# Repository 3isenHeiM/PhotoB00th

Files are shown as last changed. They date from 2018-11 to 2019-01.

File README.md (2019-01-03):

# Photob00th

A RPi photobooth for my brother's wedding, that controls a DSLR and makes a slideshow of the pictures.

Forked from kitesurfer1404's one.

Architecture : RPI for interfacing the DSLR, with arduino to command the I/Os.

## Required features
By order of importance...
* RaspberryPi-based
* Pictures from DSLR (and not Picamera module)
* LED light (because the room will be dark)
* Press button to trigger capture
* Publish the photos as slideshow on a (remote) screen
* Countdown (7-segment display ?)
* Do a Wooden enclosure

## Design

* RaspberryPi :
  * Controls the DLSR
  * Setup the slideshow
* Arduino :
  * Wait for events on the button (+ light it up with the countdown)
  * Control the 7-segment display
  * Light and dim the big LEDs

* Serial link between Arduino and RaspberryPi to exchagne commands and feeback.
* State machine running on both µcontrollers to listen for serial commands
* Based on serial commands, they can interact

## Sources :
* [Control 7-segment display using python](https://raspi.tv/2015/how-to-drive-a-7-segment-display-directly-on-raspberry-pi-in-python)
* [Example Control big button + light](https://photos.google.com/share/AF1QipOwxhytRgeDRXFwA8Ee42yeQ1euaZ-cLYzybYsmrUi8KKORaJuT7p9L6YDLRAZysg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)
* [Instagram Filters in 15 Lines of Python](https://www.practicepython.org/blog/2016/12/20/instagram-filters-python.html)
* [Background Image](https://www.pixelstalk.net/wp-content/uploads/2016/08/Damask-Desktop-Wallpaper.jpg)

## Bill of Materials :
* [Arduino Uno - R3](https://www.sparkfun.com/products/11021) - Sparkfun - 24.95$
* [Breadboard - Self-Adhesive (White)](https://www.sparkfun.com/products/12002) - Sparkfun - 4.95$
* [Big Red dome button](https://www.sparkfun.com/products/9181) - Sparkfun - 11.95$
  12V supply
* [7-Segment display 6,5"](https://www.sparkfun.com/products/8530) - Sparkfun - 18.95$
  12V supply
* [Jumper Wires Premium 4" M/M - 26 AWG (30 Pack)](https://www.sparkfun.com/products/14284) - Sparkfun - 1.95$
  (to connect with RPi)
* [Darlington Driver 8-Channel ULN2803 DIP](https://www.sparkfun.com/products/312) - Sparkfun - 1.95$
  2 pieves
* [Jumper Wire Kit - 140pcs](https://www.sparkfun.com/products/124) - Sparkfun - 5.95$
* [DC Barrel Jack Adapter - Breadboard Compatible](https://www.sparkfun.com/products/10811) - Sparkfun - 0.95$
  to bring 12V on the breadboard
* [Resistor 1K Ohm 1/4 Watt PTH - 20 pack (Thick Leads) ](https://www.sparkfun.com/products/14492) - Sparkfun - 0.95$
* [4 LED MR16 Spotlight 12V 4W](https://www.miniinthebox.com/en/p/10pcs-dimmable-mr16-4w-4x1w-400lm-warm-white-white-cool-white-led-light-spot-lamp-dc12v_p2343919.html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) - MiniInTheBox.com - 17.38€ for 10.
* [10pc MR16 Sockets](https://www.amazon.com/Glo-shine-Halogen-Ceramic-Connector-Adapter/dp/B00Y7GRGZ0) - Amazon - 7.71$
* [Arduino and Breadboard Holder](https://www.sparkfun.com/products/11235) - Sparkfun - 3.95$

## Workflow
Here is the workflow I initially intend for this project :
1. Push the red button
2. Countdown from 3 to 0 :
    - Count using the 7-segment display
    - Light up/down the red button
    - Light the LEDs
    - At "1", ask the RPi to do the focus
    - Display the camera preview on a VGA screen
3. Trigger picture and light the LEDs more
4. Download the picture (raw/jpg?) on the RaspberryPi's external storage
5. Move a jpg version to the webserver backend
6. Reset the setup

### Arduino State machine

Initial state :
 - buttonLED is "breathing" (cf Snippets.md)
 - Wait for event on the button
 - Listening for any command in the serial port

1. When button is pressed :  
    - Display "3" on 7-segment display for 1s
    - Light the button for 0.5s
2. After 1s :
    - Display "2" on the 7-segment display for 1s
    - Light the button for 0.5s
3. After 1s :
    - Display "1" on the 7-segment display for 1s
    - ~~Send command "`do_focus`" via serial to the RPi~~
    - Light the button for 0.5s
4. Take the photo :
    - Increase lights of the LED to 100%
    - Send command "`takePhoto`" via serial to the RPi
    - ~~Wait for command "`picture_taken`" from the serial port~~
5. Get back to initial state

### Raspberry Pi State machine

Initial state :
 - ~~Waiting for command "`do_focus`" from the Arduino~~
 - Listens for the command "`takePhoto`"

1. ~~When `do_focus` is received :~~
    - ~~use gphoto to do the focus (not sure if supported)~~
2. When `takePhoto` is received :
    - use gphoto to capture the image and download it
    - ~~send `picture_taken` to Arduino~~
3. Post-process the image in a separate thread :
    - Apply a filter ? (if fast enough : 3-4s)
    - Move it the the correct folder
    - Rename it
    - Update the slideshow
4. Get back to initial state

## Various details

### PWM pins on the Arduino
Reference [here](https://www.arduino.cc/reference/en/language/functions/analog-io/analogwrite/)

On most Arduino boards (those with the ATmega168 or ATmega328P), this function works on pins `3`, `5`, `6`, `9`, `10`, and `11`.
They are indicated by a `~` besides their number on the Arduino.

### How to manipulate the button
(Learned from [here](https://learn.sparkfun.com/tutorials/reaction-timer), where they featyre the exact same button

Status :
* Button pressed : `digitalRead(button) == LOW`
* Button released : `digitalRead(button) == HIGH`

Pinning :
* *NO* (normally openned) pin : button trigger
* Anode : LED anode
* GND : ground

### Darlington arrays
Nice explanation [here](https://forum.arduino.cc/index.php?topic=157018.0)

The output of the ULN2803 is not supplying anything. The ULN2803 are a bunch of darlington transistor.
They pull the output low. That is all. They have also a large voltage drop of about 1V.

Pinning :
* 1-8 (arduino) -> 18-11 (output)  
That is :
  * `pin 1` will control whatever is conected on `pin 18`
  * `pin 2` will control the output `pin 17`
    etc...
* 10 : Common -> +12V
* Ground -> Power supply Ground

The load (led+7-segment display) has 2 connections :
* +12VDC
* output pin of the matching control pin

When the control pin is high, the Darlington array pulls down the output pin (at +12V) to the Ground. And the current flows and you have current in whatever load you have put between the Darlington output pin and the power sypply.

## Stepping stones / To-Do
- [x] Dim the 12V LEDs using the Raspberry and a Darlington array (since they are 12V-powered)   
    Solution : Use an Arduino Uno for all GPIO-related events.
- [x] DSLR is not recognized by the Ubuntu   
    Solution found [here](http://www.freeklijten.nl/2011/06/04/Mounting-a-Canon-EOS-550d-on-Ubuntu-using-gphoto2#wl-comment-672)
- [x] Auto-poweroff of the USB connectivity (tests made on MacOS)  
    Solution found [here](http://gphoto-software.10949.n7.nabble.com/canon-autopoweroff-tp14943p14958.html) : use the `wait-event` function, it send a keepalive message to the camera.
    Will be tested.
    Edit : the AutoPoweroff of the CanonESO 700D has been disabled on the Camera itself.Once done, no more interruption in the gphoto detection of the camera.
- [ ] ~~Impossible to trigger the focus of the camera itself. State machine has been updated.~~  
      Impossible to do using gphoto2.
- [ ] Handles the warning exception of skimage ()'Possible precision loss when converting from float64 to uint8')
- [ ] Threadize the post-processing

## Canon EOS 700D support
I used a Canon EOS 700D DSLR camera, the [following page](CanonEOS700D.md) lists the supported operations of gphoto for this type of camera

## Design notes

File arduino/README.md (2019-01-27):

# Arduino Photobooth

This is part of the Photob00th but might be used standalone.

The Arduino interfaces will all the GPIOs (LED, buttons, etc...) and communicates via a Serial port with the Raspberry.

The Arduino is used to be able to dim the lights of the big 4 LEDs. The dim is done using PWM modulation. I could not find any resources online to execute this on the RaspBerry (with 12V LEDs).

## State machine
cf main ReadMe.md

## Updated Wiring Diagram
The connections are done using a small breadboard.

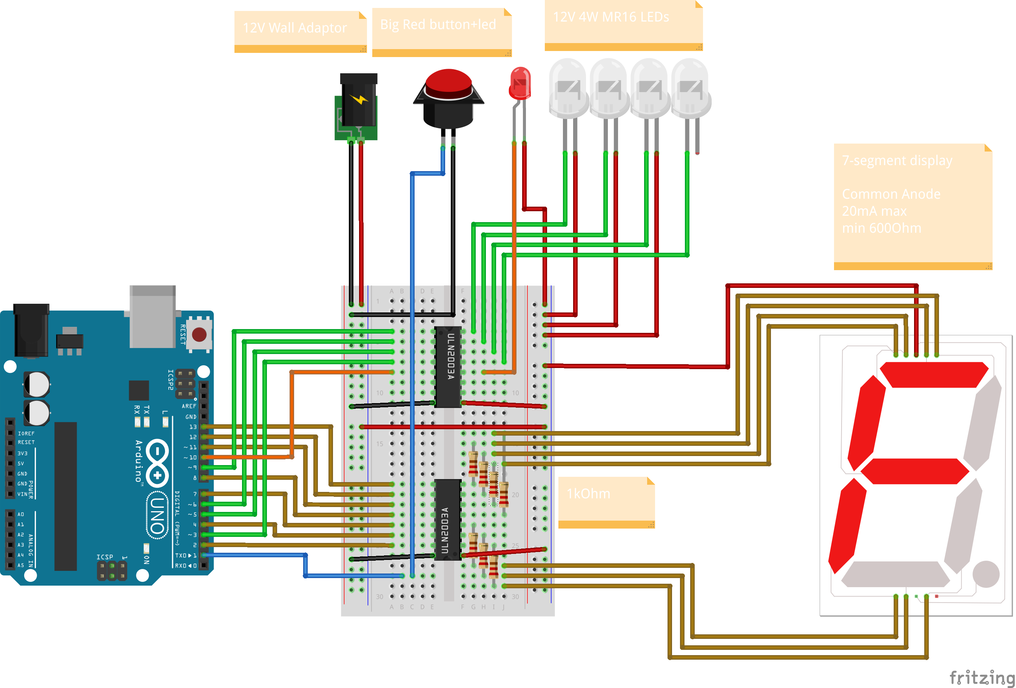
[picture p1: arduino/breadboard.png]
Arduino Photobooth


## Previous Wiring Diagram
Arduino Photobooth2

## PWM explanation
* [Controlling an LED by PWM](https://www.sunfounder.com/learn/Super-Kit-V2-0-for-Arduino/lesson-3-controlling-an-led-by-pwm-super-kit.html)
* [Fade an LED with Pulse Width Modulation using analogWrite()](https://programmingelectronics.com/tutorial-10-fade-an-led-with-pulse-width-modulation-using-analogwrite/)

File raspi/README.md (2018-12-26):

Raspberry Pi Photobooth
=======================

This part describes the setup and contains the code to be run on the RasPi.

You will need a RasPi 3 Mod. B for this setup due to image-processing-power and
WiFi capability.

If you use an older model, please adjust the WiFi as needed.

This code does NOT control the camera! Make sure the camera is triggered by
the Arduino code or cable release. The RasPi code only downloads images from the
camera after gphoto recognizes the corresponding event.

The code is mainly divided into three parts:

* slideshow running on port 8000 (http)
* script downloading and processing new images
* shutdown-script listening for pushbutton on IO for clean shutdown

photobooth.sh is the place to start your journey.

Install
-------

Install Raspian on your RasPi 3.
Setup your RasPi with raspi-config as needed. Set password.
Disable desktop if you want. Photobooth will run in terminal.

Enable SSH if needed:
```shell
sudo update-rc.d ssh defaults
sudo update-rc.d ssh enable
```

Install gphoto2 and imagemagick on your RasPi:
```shell
sudo apt install gphoto2 imagemagick libgphoto2-dev
sudo pip install pkgconfig gphoto2
```

Disable auto-mount of cameras:
```shell
sudo chmod -x /usr/lib/gvfs/gvfs-gphoto2-volume-monitor
```

Download or copy the photobooth folder to /home/pi on your RasPi.

Edit .bashrc
```shell
nano .bashrc
```

Add this to the very end:

```shell
if [ -n "$SSH_CLIENT" ] || [ -n "$SSH_TTY" ]; then
  echo "Only running on local shell."
else
  ~/photobooth/photobooth.sh
fi
```

Reboot:
```shell
sudo reboot
```

Alternatively you can add the script to the crontab and run it at reboot:

```shell
crontab -e
```

Add this line:
```
@reboot /home/pi/photobooth/photobooth.sh
```

(Adjust path accordingly)

WiFi config/AP
--------------

The RasPi is configured as a WiFi AP. This way you can connect directly to the
RasPi with your devices.

You can find a great howto here:
https://frillip.com/using-your-raspberry-pi-3-as-a-wifi-access-point-with-hostapd/

Below the bare minimum follows.

```shell
sudo apt install hostapd dnsmasq
sudo nano /etc/dhcpcd.conf
```

Add to bottom of file:
```
denyinterfaces wlan0
```

Edit network config:
```shell
sudo nano /etc/network/interfaces
```

Edit wlan0 section so it becomes this:

```
allow-hotplug wlan0
iface wlan0 inet static
    address 10.0.0.1
    netmask 255.255.255.0
    network 10.0.0.0
    broadcast 10.0.0.255
#    wpa-conf /etc/wpa_supplicant/wpa_supplicant.conf
```

Restart networking stuff

```shell
sudo service dhcpcd restart
sudo ifdown wlan0; sudo ifup wlan0
```

Edit hostapd config.

```shell
sudo nano /etc/hostapd/hostapd.conf
```

Please adjust WiFi ssid and password to your needs.

```
ssid=Photobooth-WiFi
wpa_passphrase=Smile123456
interface=wlan0
driver=nl80211
hw_mode=g
channel=6
ieee80211n=1
wmm_enabled=1
ht_capab=[HT40][SHORT-GI-20][DSSS_CCK-40]
macaddr_acl=0
auth_algs=1
ignore_broadcast_ssid=0
wpa=2
wpa_key_mgmt=WPA-PSK
rsn_pairwise=CCMP
```

Test
```shell
sudo /usr/sbin/hostapd /etc/hostapd/hostapd.conf
```

You should now see Photobooth-WiFi floating around. Quit:
```shell
Ctrl-C
```

Start WiFi AP as daemon:
```shell
sudo nano /etc/default/hostapd
```

Edit config to
```
DAEMON_CONF="/etc/hostapd/hostapd.conf"
```

Let's make sure we even get an IP address when using the WiFi:
```shell
sudo mv /etc/dnsmasq.conf /etc/dnsmasq.conf.orig
sudo nano /etc/dnsmasq.conf
```

```
interface=wlan0      # Use interface wlan0
listen-address=10.0.0.1 # Explicitly specify the address to listen on
bind-interfaces      # Bind to the interface to make sure we aren't sending things elsewhere
server=10.0.0.1      # Answer DNS request by self
domain-needed        # Don't forward short names
bogus-priv           # Never forward addresses in the non-routed address spaces.
dhcp-range=10.0.0.50,10.0.0.150,24h # Assign IP addresses between 10.0.0.50 and 10.0.0.150 with a 24 hour lease time
```

```shell
sudo service hostapd start
sudo service dnsmasq start
```

Check. Double check.

```shell
sudo reboot
```

Check again.

Shutdown script
---------------

We need a nice shutdown of the RasPi so no data is getting lost. I wrote a small
shutdown.py script that listens to one of the IO-pins. If pin is connected to
GND, the script calls sudo halt.

Connect a momentary switch between Pin 26 and GND on the GPIOs.

If you want to skip this, shutdown with a keyboard or so.

You might also want to try to add dtoverlay=gpio-shutdown,gpio-pin=X to /boot/config.txt (Thanks to @sxwid) instead of using the shutdown script.

(Almost) Done!
--------------

Please refer to the gphoto section below for gphoto setup for your specific camera model!

You might then reboot and enjoy the photobooth slideshow on
http://10.0.0.1:8000

Detailed information on the Hows and Whys
=========================================

Main Control
------------

All needed processes are started by photobooth.sh which runs at startup.

gphoto
------

All the communication with the camera is done by gphoto2.
Please check their documentation to get your camera hooked up.

Photos are stored on the cameras memory card. This is set in photobooth.sh with:

```shell
gphoto2 --set-config-index /main/settings/capturetarget=1
```

You might want to adjust that command to your camera needs. Find the right
capturetarget with this command and identify the correct choice:

```shell
gphoto2 --get-config=capturetarget
```

```
Label: Capture Target                                                          
Type: RADIO
Current: Internal RAM
Choice: 0 Internal RAM
*Choice: 1 Memory card*
```

Try to set manually:

```shell
gphoto2 --set-config-index /main/settings/capturetarget=1
```

Check:

```shell
gphoto2 --get-config=capturetarget
```

```
Label: Capture Target                                                          
Type: RADIO
*Current: Memory card*
Choice: 0 Internal RAM
Choice: 1 Memory card
```

**Update photobooth.sh to your needs.**

gphoto waits for a photo to be taken and then downloads the photo to the
RasPi. After downloading, the images are processed by postprocessing.sh

You can test this manually if needed:

```shell
gphoto2 --wait-event-and-download --keep --hook-script=postprocessing.sh
```

At the moment RAW-files are just moved to images/raw
JPEGs are processed with imagemagicks convert command. You might want to check
the options in postprocessing.sh and adjust them to your needs.

Slideshow
---------

There is a minimal webserver running on port 8000. See server.py for details.
index.html redirects the viewer to the slideshow.

Mainly it is requesting the image-count on the RasPi and enques all new images
to the slideshow. This is done by an ajax-request for /image_count.txt on the
server. Then filenames and paths are generated in javascript.
Take a look at slideshow/index.html and the JS-vars image_path and image_extension
You need to adjust these to chances in the postprocessing.sh accordingly.

The slideshow is optimized for 1920x1080 screens.
Modify #slideshow and #slideshow img in slideshow.css to your needs.

Credits for the Ken Burns effect go to:

http://cssmojo.com/ken-burns-effect/
http://www.css-101.org/articles/ken-burns_effect/css-transition.php

### Image resising

resize.py takes car of resinsing the image to a FullHD (1920x1080). Inspired from [here](https://www.blog.pythonlibrary.org/2017/10/12/how-to-resize-a-photo-with-python/)
```
# python resize.py
  Original image : 5184x3456
  Scaled image : 1920x1280
  Elapsed time: 1.178s
```

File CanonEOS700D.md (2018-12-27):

# Canon EOS 700D and gphoto2

` gphoto2 --capture-image-and-download --filename "%Y-%m-%d %H:%M:%S.jpg" `

## Supported operations
```
gphoto2 --list-config
/main/actions/syncdatetimeutc
/main/actions/syncdatetime
/main/actions/uilock
/main/actions/autofocusdrive
/main/actions/manualfocusdrive
/main/actions/cancelautofocus
/main/actions/eoszoom
/main/actions/eoszoomposition
/main/actions/viewfinder
/main/actions/eosremoterelease
/main/actions/opcode
/main/settings/datetimeutc
/main/settings/datetime
/main/settings/reviewtime
/main/settings/output
/main/settings/movierecordtarget
/main/settings/evfmode
/main/settings/ownername
/main/settings/artist
/main/settings/copyright
/main/settings/customfuncex
/main/settings/focusinfo
/main/settings/focusarea
/main/settings/autopoweroff
/main/settings/depthoffield
/main/settings/capturetarget
/main/settings/capture
/main/status/serialnumber
/main/status/manufacturer
/main/status/cameramodel
/main/status/deviceversion
/main/status/vendorextension
/main/status/model
/main/status/ptpversion
/main/status/Battery Level
/main/status/batterylevel
/main/status/lensname
/main/status/eosserialnumber
/main/status/shuttercounter
/main/status/availableshots
/main/imgsettings/imageformat
/main/imgsettings/imageformatsd
/main/imgsettings/iso
/main/imgsettings/whitebalance
/main/imgsettings/colortemperature
/main/imgsettings/whitebalanceadjusta
/main/imgsettings/whitebalanceadjustb
/main/imgsettings/whitebalancexa
/main/imgsettings/whitebalancexb
/main/imgsettings/colorspace
/main/capturesettings/exposurecompensation
/main/capturesettings/focusmode
/main/capturesettings/continuousaf
/main/capturesettings/aspectratio
/main/capturesettings/storageid
/main/capturesettings/highisonr
/main/capturesettings/autoexposuremode
/main/capturesettings/drivemode
/main/capturesettings/picturestyle
/main/capturesettings/aperture
/main/capturesettings/shutterspeed
/main/capturesettings/meteringmode
/main/capturesettings/bracketmode
/main/capturesettings/aeb
/main/other/d402
/main/other/d407
/main/other/d406
/main/other/d303
/main/other/5001
```

## Various operations

### Battery Level
I think that the camera is powered by the UBS cable, so there's no worry about running out of battery when it's USB-connected.
```
# gphoto2 --get-config batterylevel
Label: Battery Level
Readonly: 1
Type: TEXT
Current: 100%
END
```
### AutoPowerOff

```
# gphoto2 --get-config autopoweroff
Label: Auto Power Off
Readonly: 0
Type: TEXT
Current: 30
END
```

### Set Manual Focus
`--set-config manualfocusdrive=Mode` where mode is "Near 1" "Near 2" "Near 3" "Far 1" "Far 2" "Far 3".
These are 3 different relative stepsizes for both focusing directions. To achieve focusing, multiple calls might need to be done.

### Time difference

1. Capture target on internal memory   
`gphoto2 --set-config-index /main/settings/capturetarget=0`  

```
time gphoto2 --capture-image-and-download --filename "%Y-%m-%d_%H:%M:%S.jpg"
New file is in location /capt0000.jpg on the camera
Saving file as 2018-11-30_20:18:22.jpg
Deleting file /capt0000.jpg on the camera
gphoto2 --capture-image-and-download --filename "%Y-%m-%d_%H:%M:%S.jpg"  0.14s user 0.11s system 7% cpu 3.431 total
```
2. Capture target on SD card
`gphoto2 --set-config-index /main/settings/capturetarget=1`  

```
time gphoto2 --capture-image-and-download --filename "%Y-%m-%d_%H:%M:%S.jpg"
New file is in location /store_00020001/DCIM/100CANON/IMG_2523.JPG on the camera
Saving file as 2018-11-30_21:22:42.jpg
Deleting file /store_00020001/DCIM/100CANON/IMG_2523.JPG on the camera
gphoto2 --capture-image-and-download --filename "%Y-%m-%d_%H:%M:%S.jpg"  0.13s user 0.15s system 4% cpu 6.517 total
```

## Useful links
* [gphoto on MacOS](http://photolifetoys.blogspot.com/2012/08/control-your-camera-with-gphoto2-via.html)

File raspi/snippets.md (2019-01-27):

# Code snippets

Those are a collection of snippets I fetched during my investigation on how to do it...

---
## List the capabilities of a camera :
`gphoto2 --list-all-config >config.txt`

Display `config.txt` to see what is supported.

---
## Disable IPv6 on Raspberry
Reference [here](https://askubuntu.com/a/309463/217297)

---
## Python Serial port and commands
Reference [here](https://stackoverflow.com/questions/676172/full-examples-of-using-pyserial-package)

```
import time
import serial

# configure the serial connections (the parameters differs on the device you are connecting to)
ser = serial.Serial(
    port='/dev/ttyUSB1',
    baudrate=9600,
    parity=serial.PARITY_ODD,
    stopbits=serial.STOPBITS_TWO,
    bytesize=serial.SEVENBITS
)

ser.isOpen()

print 'Enter your commands below.\r\nInsert "exit" to leave the application.'

input=1
while 1 :
    # get keyboard input
    input = raw_input(">> ")
        # Python 3 users
        # input = input(">> ")
    if input == 'exit':
        ser.close()
        exit()
    else:
        # send the character to the device
        # (note that I happend a \r\n carriage return and line feed to the characters - this is requested by my device)
        ser.write(input + '\r\n')
        out = ''
        # let's wait one second before reading output (let's give device time to answer)
        time.sleep(1)
        while ser.inWaiting() > 0:
            out += ser.read(1)

        if out != '':
          print ">>" + out
```

---
## Capture and download using python

From python-gphoto2 [examples](https://github.com/jim-easterbrook/python-gphoto2/blob/master/examples/capture-image.py).
Two functions are used :
* `gp.gp_camera_capture(camera, gp.GP_CAPTURE_IMAGE)`  
to trigger the shot
* `gp.gp_camera_file_get(camera, file_path.folder, file_path.name, gp.GP_FILE_TYPE_NORMAL)`  
to download the image

```
#!/usr/bin/env python

# python-gphoto2 - Python interface to libgphoto2
# http://github.com/jim-easterbrook/python-gphoto2
# Copyright (C) 2015-17  Jim Easterbrook  jim@jim-easterbrook.me.uk
#
# This program is free software: you can redistribute it and/or modify
# it under the terms of the GNU General Public License as published by
# the Free Software Foundation, either version 3 of the License, or
# (at your option) any later version.
#
# This program is distributed in the hope that it will be useful,
# but WITHOUT ANY WARRANTY; without even the implied warranty of
# MERCHANTABILITY or FITNESS FOR A PARTICULAR PURPOSE.  See the
# GNU General Public License for more details.
#
# You should have received a copy of the GNU General Public License
# along with this program.  If not, see <http://www.gnu.org/licenses/>.

from __future__ import print_function

import logging
import os
import subprocess
import sys

import gphoto2 as gp

def main():
    logging.basicConfig(
        format='%(levelname)s: %(name)s: %(message)s', level=logging.WARNING)
    gp.check_result(gp.use_python_logging())
    camera = gp.check_result(gp.gp_camera_new())
    gp.check_result(gp.gp_camera_init(camera))
    print('Capturing image')
    file_path = gp.check_result(gp.gp_camera_capture(
        camera, gp.GP_CAPTURE_IMAGE))
    print('Camera file path: {0}/{1}'.format(file_path.folder, file_path.name))
    target = os.path.join('/tmp', file_path.name)
    print('Copying image to', target)
    camera_file = gp.check_result(gp.gp_camera_file_get(
            camera, file_path.folder, file_path.name, gp.GP_FILE_TYPE_NORMAL))
    gp.check_result(gp.gp_file_save(camera_file, target))
    subprocess.call(['xdg-open', target]) # To open the image in the preferred editor
    gp.check_result(gp.gp_camera_exit(camera))
    return 0

if __name__ == "__main__":
sys.exit(main())
```

---
## Serial communication with an Arduino

from [here](https://stackoverflow.com/a/24075787/3494633)

```
#!/usr/bin/python
import serial
import syslog
import time

#The following line is for serial over GPIO
port = '/dev/tty.usbmodem1411' # note I'm using Mac OS-X

ard = serial.Serial(port,9600,timeout=5)
time.sleep(2) # wait for Arduino

i = 0

while (i < 4):
    # Serial write section

    setTempCar1 = 63
    setTempCar2 = 37
    ard.flush()
    setTemp1 = str(setTempCar1)
    setTemp2 = str(setTempCar2)
    print ("Python value sent: ")
    print (setTemp1)
    ard.write(setTemp1)
    time.sleep(1) # I shortened this to match the new value in your Arduino code

    # Serial read section
    msg = ard.read(ard.inWaiting()) # read all characters in buffer
    print ("Message from arduino: ")
    print (msg)
    i = i + 1
else:
    print "Exiting"
exit()
```

---
## Resize image to 1080p

`resize.py` takes car of resizing the image to a FullHD (1920x1080). Inspired from [here](https://www.blog.pythonlibrary.org/2017/10/12/how-to-resize-a-photo-with-python/)
```
# python resize.py
  Original image : 5184x3456
  Scaled image : 1920x1280
  Elapsed time: 1.178s
```

resize.py :
```
from PIL import Image
import time

def scale_image(input_image_path,
                output_image_path,
                width=None,
                height=None
                ):
    original_image = Image.open(input_image_path)
    w, h = original_image.size
    print('Original image : {wide}x{height} '
          'high'.format(wide=w, height=h))

    if width and height:
        max_size = (width, height)
    elif width:
        max_size = (width, h)
    elif height:
        max_size = (w, height)
    else:
        # No width or height specified
        raise RuntimeError('Width or height required!')

    original_image.thumbnail(max_size, Image.ANTIALIAS)
    original_image.save(output_image_path)

    scaled_image = Image.open(output_image_path)
    width, height = scaled_image.size
    print('Scaled image : {wide}x{height} '
          'high'.format(wide=width, height=height))

if __name__ == '__main__':

    start = time.time()

    scale_image(input_image_path='2018-11-30_20:12:39.jpg',
                output_image_path='2018-11-30_20:12:39_scaled.jpg',
                width=1920)

    elapsed = time.time() - start
    print 'Elapsed time: %.3fs' % (elapsed)
```

---
## Standalone Photobooth using RPi only

from [here](https://github.com/feiticeir0/RPiPhotoBooth/blob/master/RPiPhotoBooth.py)

```
# Testing here
while (True):
	try:
		camera.start_preview()      # <--- To be replaced by the libphoto function
		#Show LED Only for Take Picture
		onlyTakePicLed()
		# Wait for button to take Picture
		GPIO.wait_for_edge(takeButton,GPIO.FALLING)
		# Start a thread to count with the LEDs while the images are shown
		# Probably could be used in the overlayCounter function,
		# because it also as timers to show the pictures, but the led effects would not
		# be the same
		thread.start_new_thread ( countingTimerPicture,() )

		# Show the pictures overlay in the camera picture
		overlayCounter()
		# Show all LEDS while taking the picture
		showAllLeds()

		# Define a filename and path
		filename = "fotos/%s.jpg" % (time.strftime("%G%m%d%H%M%S"))
		# camera.capture('pushTesting.jpg')
		camera.capture(filename)
		camera.stop_preview()

		#display image
		# Resize and display the resized one
		#filename_t = "fotos/resized_t.jpg"
		# resizeThumbnail(filename)
		displayPreview(filename)
		# Show overlay
		oo = overlaysn()
		# While not choosing an option
		### Add a callback
		####GPIO.add_event_detect(socialNetworkButton,GPIO.FALLING,callback=tweetImage,bouncetime=300)
		###while (True):
		###	GPIO.wait_for_edge(cancelButton, GPIO.FALLING)
		####	print ("cancelled Button")
		##	break
		# Show LEDs to Cancel or Post to Social Networks
		cancelPostLEDS()
		GPIO.add_event_detect(socialNetworkButton,GPIO.FALLING)
		GPIO.add_event_detect(cancelButton,GPIO.FALLING)
		while (True):
			if GPIO.event_detected(socialNetworkButton):
				camera.remove_overlay(oo)
				GPIO.output(cancelButtonLed,False)
				o = displayPreview3('Aenviar.png')
				#print "Social Networks Button"
				# add watermark
				# Only add watermark if sending to social networks
				addWaterMark()
				sendToTwitter()
				sendToFacebook()
				camera.remove_overlay(o)
				break
			if GPIO.event_detected(cancelButton):
				#print "Canceled"
				camera.remove_overlay(oo)
				break

		# reset GPIOS
		GPIO.remove_event_detect(socialNetworkButton)
		GPIO.remove_event_detect(cancelButton)
		GPIO.remove_event_detect(takeButton)
		camera.stop_preview()
	except KeyboardInterrupt:
		print ("Exited...")
		#offLeds()
GPIO.cleanup()
```

---

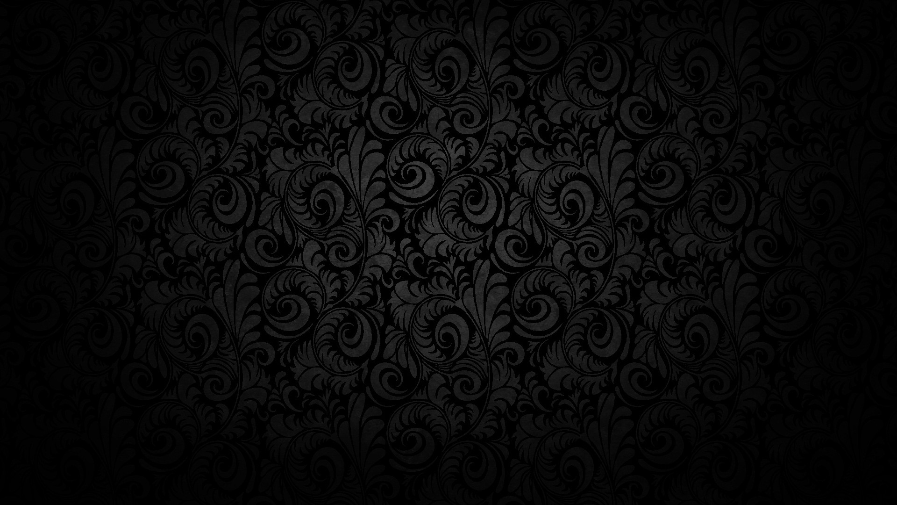
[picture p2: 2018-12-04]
raspi/photobooth/slideshow/background_3.jpg

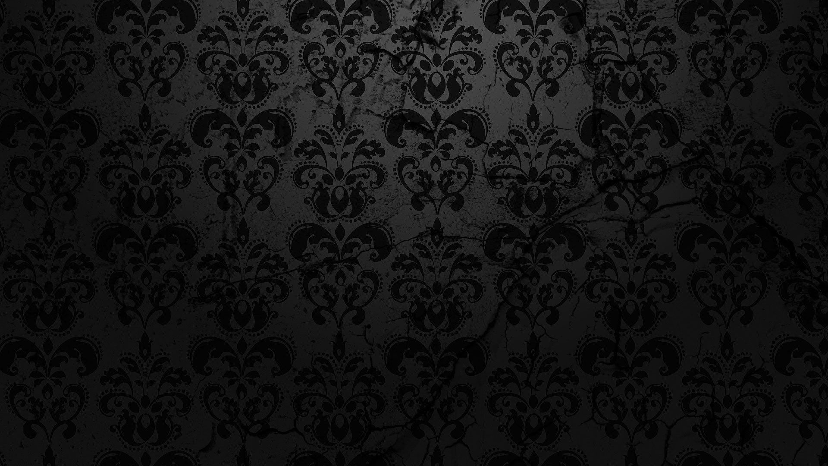
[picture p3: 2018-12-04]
raspi/photobooth/slideshow/background_2.jpg

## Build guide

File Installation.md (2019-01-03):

# Installation

For the original project I used an Odroid C2 instead of a RapsberryPi 3B+.

This is thus divide din to 2 parts :
* Installation on Odroid C2
* Installation on raspberry Pi

## Installation on Odroid C2

### Python modules to Install

To be installed using pip (`pip install <package_name>`) :
* pyserial
* RPi.GPIO

### Installation of GPhoto

Installation of libgphoto-device
`$ sudo apt install gphoto2 libgphoto2-dev`

Installation of gphoto using pip (from [here](https://github.com/jim-easterbrook/python-gphoto2#install-with-pip))
`$ sudo pip install gphoto2`

### Use RPi.GPIO

TO use the GPIOs on the Odroid C2, first we have to install a library to allow us to use the same library as for the Rapsberry Pi. Useful doc is (here)[https://github.com/jfath/RPi.GPIO-Odroid]

### Installation of Skimage
1. Install SciPy following [this guide](https://www.scipy.org/install.html). Basically running this (it will download approx 1.6 GB data !):  
`sudo apt-get install python-numpy python-scipy python-matplotlib ipython python-pandas python-sympy python-nose`

2. Install Cython (required to build scikit-image)  
`sudo apt install cython`

3. Install `scikit-image` (new version of `skimage`)  
`sudo pip install scikit-image`

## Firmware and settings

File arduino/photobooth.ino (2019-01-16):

/*
  Arduino Photobooth

  FEATURES
    * 7-segment-display for countdown
    * LED-speedlights
    * "breathing" pushbutton-LED
    * Standalone or remote controlled operation (USB-serial)


  NOTES
    * Pushbutton-pins are configured to use internal pullup resistors
      of the Arduino for less external parts. If you want to use external
      pullup resistors change INPUT_PULLUP to INPUT in setup().
    * Set your camera to continuous focus for best results.
    * Use exposure compensation to compensate the dimmed focusing light.
      Values arround -1 EV work best for me in low light situations.
    * You might also need to adjust values in takePhoto() to your needs.
      Brightness and delays might be different with different LED-bulbs.
    * Serial speed is 9600 Baud. See processCommand() for a complete
      list of supported commands.
    * There is support for multiple pushbuttons - although only one is used
      by now. When connecting to a Raspberry Pi a second pushbutton might be
      used to shut the Pi down due to its lack of a power-down-button.
    * analogWrite() works only on Pins 3, 5, 6, 9, 10, 11 - that's why the LED-spots
      are connected to pins 10, 11, 5, 6 so we can get dimmed focusing light.
    * Make sure to connect all pushbutton LEDs to PWM outputs so the breathing
      will work.
    * Read the datasheet of your 7-segment-display for pin-layout.
      Connect this way:

       Segment     Pin (7-segment) Pin (Darlington)    Pin (Arduino)
          A         1               1-18                13
          B         8               4                   8
          C         7               7                   2
          D         6               6                   4
          E         4               5                   7
          F         2               2                   12
          G         3               3                   11
          DP        9               --

      Use darlington array and and current limiting resistors as appropriate.
    * See repository for example circuit.

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

  LICENSE

  The MIT License (MIT)

  Copyright (c) 2015  Harm Aldick

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

  CHANGELOG

  2016-01-16   Initial beta release

*/


/* This is where you might define different IO-pins */

int segment_pins[] = { 8, 2, 13, 4, 7, 12, 11}; // pins segments A-G of the display are connected to
//int segment_pins[] = { 13, 8, 2, 4, 7, 12, 11}; // pins segments A-G of the display are connected to
int spot_pins[] = { 9, 6, 5, 3};             // pins the spot-lights are connected to, use PWM-pins here

// TODO : check numbering of the A0 pin of the Arduino
int button_led[] = { 10 };  // pin on which the LED of the pushbutton-switch is connected to. Use PWM-pins here.
int button_pin[] = { 1 }; // pin on which the pushbutton(s) is/are connected to. Using analog pin A0 as digital input
int lastButtonState[] = { 1 };  // saving the last state(s) of the button(s)


/* Some magic configuration happening below. */

byte segment_digits[10][7] = { // segments to light up on the corresponding index
  { 1,1,1,1,1,1,0 },    // 0
  { 0,1,1,0,0,0,0 },    // 1
  { 1,1,0,1,1,0,1 },    // 2
  { 1,1,1,1,0,0,1 },    // 3
  { 0,1,1,0,0,1,1 },    // 4
  { 1,0,1,1,0,1,1 },    // 5
  { 1,0,1,1,1,1,1 },    // 6
  { 1,1,1,0,0,0,0 },    // 7
  { 1,1,1,1,1,1,1 },    // 8
  { 1,1,1,1,0,1,1 }     // 9
};

int breath_delay_steps[] =       {   7,   9,  13, 15, 16, 17, 18, 930, 19, 18, 15, 13,   9,   7,   4,   5 }; // magic numbers for breathing LED
int breath_brightness_steps[] =  { 150, 125, 100, 75, 50, 25, 16,  15, 16, 25, 50, 75, 100, 125, 150, 220 }; // even more magic numbers!

// initial/default values for breathing LED
#define breath_initial_brightness 15
#define breath_initial_direction 1
#define breath_initial_index 8
#define breath_initial_delay 1

int breath_brightness; // initial brightness of breathing LED
int breath_direction;  // increase brightness
int breath_index;      // start at index 8 of our magic numbers
int breath_delay;      // no delay at startup, load values imidiately
boolean breathing_enabled = true;  // enables/disables breathing LED at all.

String inputCommand = "";         // a string to hold incoming data from serial
boolean commandComplete = false;  // whether the command string is complete

boolean mode_auto = true; // default is running in standalone-mode



// The setup function runs once when you press reset or power the board.
void setup() {
  // Set all 7-segment-pins as output and turn LEDs off
  for(int i = 0; i < sizeof(segment_pins)/sizeof(int); i++) {
    pinMode(segment_pins[i], OUTPUT);
    digitalWrite(segment_pins[i], LOW);
  }

  // Turn all spotsOff.
  for(int i = 0; i < sizeof(spot_pins)/sizeof(int); i++) {
    digitalWrite(spot_pins[i], 0);
  }

  // Set all pushbutton-LED-pins as output and turn LEDs off
  for(int i = 0; i < sizeof(button_led)/sizeof(int); i++) {
    pinMode(button_led[i], OUTPUT);
    digitalWrite(button_led[i], LOW);
  }

  // Set all pushbutton-pins as input and enable pullup resistor
  for(int i = 0; i < sizeof(button_pin)/sizeof(int); i++) {
    pinMode(button_pin[i], INPUT_PULLUP); // change INPUT_PULLUP to INPUT when there is an external pullup-resistor attached
  }

  Serial.begin(115200); // initialize serial

  inputCommand.reserve(100); // reserve 100 bytes for the inputCommand

  breathing_reset(); // reset breathing LEDs

  Serial.println("ready"); // we're ready to rock!
}


/* turns all breathing LEDs gently on and resets everything for restart breathing */
void breathing_reset() {
  for(int i = 0; i <= 15; i++) {
    for(int p = 0; p < sizeof(button_led)/sizeof(int); p++) {
      analogWrite(button_led[p], i);
    }
    delay(10);
  }

  breathing_enabled = true;
  breath_brightness = breath_initial_brightness;
  breath_direction = breath_initial_direction;
  breath_index = breath_initial_index;
  breath_delay = breath_initial_delay;
}


/* turns all breathing LEDs off and disables breathing at all */
void breathing_stop() {
  for(int i = 0; i < sizeof(button_led)/sizeof(int); i++) {
    analogWrite(button_led[i], 0);
  }
  breathing_enabled = false;
}


/* does one step in "breathing", so we don't block anything else too long. */
void breathing_do_step() {
  if(!breathing_enabled) {
    return;  // nothing to do if disabled
  }

  breath_delay--;

  // update brightness and delays when waited long enough
  if(breath_delay == 0) {
    // increase or decrese brightness
    breath_brightness = breath_brightness + breath_direction;

    // change direction when LED is fully lit or very dimm
    if(breath_brightness == 255 || breath_brightness == 15) {
      breath_direction *= -1;
    }

    // update index of current delay when target brightness is reached
    if(breath_brightness == breath_brightness_steps[breath_index]) {
      breath_index++;

      // start over when the end is reached
      if(breath_index == sizeof(breath_brightness_steps)/sizeof(int)) {
        breath_index = 0;
      }
    }

    // get new delay
    breath_delay = breath_delay_steps[breath_index];

    // set new brightness to all pushbutton leds
    for(int i = 0; i < sizeof(button_led)/sizeof(int); i++) {
      analogWrite(button_led[i], breath_brightness);
    }

  } else {
    delay(1); // if we have still some rounds to go, wait 1ms and return
  }
}


/* flashes the 7-segment-display in a fancy way */
void animation_one(int wait) {
  for (int i = 0; i < sizeof(segment_pins)/sizeof(int); i++) {
    digitalWrite(segment_pins[i], LOW);
  }

  for(int n = 0; n < 5; n++) {
    for (int i = 0; i < 6; i++) {
      digitalWrite(segment_pins[i], HIGH);
      delay(wait);
      digitalWrite(segment_pins[i], LOW);
    }
  }
}


/* flashes the 7-segment-display in another fancy way */
void animation_two(int wait) {
  int animation[] = { 1, 2, 7, 5, 4, 3, 7, 6 };

  for (int i = 0; i < sizeof(segment_pins)/sizeof(int); i++) {
    digitalWrite(segment_pins[i], LOW);
  }

  for(int n = 0; n < 5; n++) {
    for(int i = 0; i < 8; i++) {
      int segment = animation[i] - 1;
      digitalWrite(segment_pins[segment], HIGH);
      delay(wait);
      digitalWrite(segment_pins[segment], LOW);
    }
  }
}


/* flashes the spots in a fancy way */
void animation_spots(int wait) {
  for (int i = 0; i < sizeof(spot_pins)/sizeof(int); i++) {
    spot_off(i);
  }

  for (int i = 0; i < sizeof(spot_pins)/sizeof(int); i++) {
    spot_on(i);
    delay(wait);
    spot_off(i);
  }
}


/* turns the LED on the button on */
void button_led_on(){
  for(int i = 0; i < sizeof(button_led)/sizeof(int); i++) {
    analogWrite(button_led[i], 255);
  }
}


/* turns the LED on the button on */
void button_led_off(){
  for(int i = 0; i < sizeof(button_led)/sizeof(int); i++) {
    analogWrite(button_led[i], 0);
  }
}

/* turns a single spot on */
void spot_on(int i) {
  analogWrite(spot_pins[i], 255);
}


/* turns a single spot off */
void spot_off(int i) {
  analogWrite(spot_pins[i], 0);
}


/* turns all spotsOn ("speedlight") */
void spots_on() {
  for (int i = 0; i < sizeof(spot_pins)/sizeof(int); i++) {
    spot_on(i);
  }
}


/* turns all spotsOff */
void spots_off() {
  for (int i = 0; i < sizeof(spot_pins)/sizeof(int); i++) {
    spot_off(i);
  }
}


/* turns all spotsOn (dimmed) for fucusing the camera in low light */
void spots_dimm(int value) {
  for (int i = 0; i < sizeof(spot_pins)/sizeof(int); i++) {
    analogWrite(spot_pins[i], value);
  }
}




/* displays a number on the 7-segment-display */
void displayNumber(int n) {
  for (int i = 0; i < sizeof(segment_pins)/sizeof(int); i++) {
    digitalWrite(segment_pins[i], segment_digits[n][i]);
  }
}


/* turns the 7-segment-displayOff */
void display_off() {
  for (int i = 0; i < sizeof(segment_pins)/sizeof(int); i++) {
    digitalWrite(segment_pins[i], LOW);
  }
}


/* turns every light off */
void clearAll() {
  spots_off();
  display_off();
  breathing_stop();
}


/* starts countdown and focusing, than takes picture */
void takePhoto() {
  //Serial.println("Taking photo.");

  animation_one(50);

  spots_dimm(5);

  // Display 3 and light the button_led
  button_led_on();
  displayNumber(3);
  delay(500);

  // Switch the button_led off
  button_led_off();
  delay(500);

  // Display a 2 and light the button_led
  button_led_on();
  displayNumber(2);
  delay(500);

  // Switch the button_led off
  button_led_off();
  delay(500);

  // Display a 1 and light the button_led
  button_led_on();
  displayNumber(1);
  delay(500);

  // Switch the button_led off
  button_led_off();
  delay(300);
  display_off();

  button_led_on();

  // Slight increase of the luminosity
  spots_dimm(20);
  delay(50);
  spots_dimm(40);
  delay(50);
  spots_dimm(60);
  delay(50);
  spots_dimm(80);
  delay(50);

  // Triggers camera on the RaspberryPi
  Serial.println("takePhoto");

  // Make the LED button blink
  for (int i = 0; i < 15; i++) {
    button_led_off();
    delay(50);
    button_led_on();
    delay(50);
  }

  // Full brightness of the LED spots
  spots_on();

  // Make the LED button blink
  for (int i = 0; i < 10; i++) {
    button_led_off();
    delay(50);
    button_led_on();
    delay(50);
  }

  delay(500);
  spots_dimm(80);
  delay(50);
  spots_dimm(60);
  delay(50);
  spots_dimm(40);
  delay(50);
  spots_dimm(20); 
  delay(50);
  spots_dimm(5);
  delay(50); 
  
  
  clearAll();

  //Serial.println("Photo taken.");
}


/* checks received command and calls corresponding function */
void processCommand(String cmd) {
  if(cmd == "1") displayNumber(1);
  if(cmd == "2") displayNumber(2);
  if(cmd == "3") displayNumber(3);
  if(cmd == "4") displayNumber(4);
  if(cmd == "5") displayNumber(5);
  if(cmd == "6") displayNumber(6);
  if(cmd == "7") displayNumber(7);
  if(cmd == "8") displayNumber(8);
  if(cmd == "9") displayNumber(9);
  if(cmd == "0") displayNumber(0);

  if(cmd == "displayOff") display_off();

  if(cmd == "spotsOn") spots_on();
  if(cmd == "spotsOff") spots_off();
  if(cmd == "spotsDimm") spots_dimm(1);

  if(cmd == "S1_on") spot_on(0);
  if(cmd == "S1_off") spot_off(0);
  if(cmd == "S2_on") spot_on(1);
  if(cmd == "S2_off") spot_off(1);
  if(cmd == "S3_on") spot_on(2);
  if(cmd == "S3_off") spot_off(2);
  if(cmd == "S4_on") spot_on(3);
  if(cmd == "S4_off") spot_off(3);

  if(cmd == "animation1") animation_one(50);
  if(cmd == "animation2") animation_two(50);
  if(cmd == "animationSpots") animation_spots(100);

  if(cmd == "clear") clearAll();

  if(cmd == "modeAuto") mode_auto = true;
  if(cmd == "modeManual") mode_auto = false;

  if(cmd == "takePhoto") takePhoto();
}


/* reads new input from serial to commandstring. Command is complete on \n */
void serialEvent() {
  while(Serial.available()) {
    char inChar = (char)Serial.read();
    if(inChar == '\n') {
      commandComplete = true;
    } else {
      inputCommand += inChar;
    }
  }
}

/* This loop function runs over and over again. */
void loop() {

  breathing_do_step(); // do one step in "breathing"

  // check pushbuttons for changes
  for(int i = 0; i < sizeof(button_pin)/sizeof(int); i++) {
    if(digitalRead(button_pin[i]) == LOW) {           // if button is pressed
      if (lastButtonState[i] == HIGH) {               // and was not pressed before
        lastButtonState[i] = LOW;                     // save current state (pressed)
        if(mode_auto) {                               // in standalone-mode...
          inputCommand = "takePhoto";                // set command
          commandComplete = true;
        } else {                                      // in remote-controlled mode...
          Serial.println("buttonPressed");             // notify computer to take a photo
        }
      }
      delay(250);                                  // poor mans debouncing
    } else {                                        // if button is not pressed
      lastButtonState[i] = HIGH;                   // save state (released)
    }
  }


  if(commandComplete) {
    breathing_stop();             // stop breathing (turn LED off)
    processCommand(inputCommand); // process command
    breathing_reset();            // enable breathing again

    inputCommand = "";            // reset the commandstring
    commandComplete = false;      // reset command complete

    Serial.println("ready");      // notify computer
  }
}

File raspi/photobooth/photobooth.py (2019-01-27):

#!/usr/bin/python
# -*- coding: utf-8 -*-

import os, os.path
import sys
import time
import signal
import traceback
import logging
from logging import handlers
import argparse
import gzip
import gphoto2 as gp
import serial
import threading
import SimpleHTTPServer
import SocketServer

# Project-related imports
import photobooth_serial as pb_serial
import photobooth_camera as pb_camera
import photobooth_image as pb_image

#####################################
# FUNCTIONS
#####################################
# Manage Ctrl+C gracefully
def signal_handler_quit(signal, frame):
    logging.info("Shutting down requested")

    webserver.shutdown()
    logging.debug("Webserver shutdown")

    gp.check_result(gp.gp_camera_exit(camera))
    logging.info("Releasing camera")

    logging.critical("Photob00th shutdown.\n")
    sys.exit(0)


# Class to create the WebServer and to log the requests in a separate file
class CustomHTTPRequestHandler(SimpleHTTPServer.SimpleHTTPRequestHandler):
    def end_headers(self):
        self.send_header("Access-Control-Allow-Origin", "*")
        SimpleHTTPServer.SimpleHTTPRequestHandler.end_headers(self)

    # Logs in a separated file
    buffer = 1
    logfile = "webserver.log"
    log_file = open(logfile, 'w', buffer)
    logging.info('Web Server logs are in %s' %logfile )
    def log_message(self, format, *args):
        self.log_file.write("%s - [%s] : %s\n" %(
            self.client_address[0],self.log_date_time_string(),format%args))


#################################
# LOGGING
#################################

# Convert verbose count in loggin level for the loggin module
def logging_level(verbosity):
    levels = [
        logging.CRITICAL,   # 50
        logging.ERROR,      # 40
        logging.WARNING,    # 30
        logging.INFO,       # 20
        logging.DEBUG       # 10
    ]
    return levels[max(min(len(levels) - 1, verbosity), 0)]

def configureLogging(numeric_level, logfile, console):
    ## VARIABLES
    format_entry = '%(asctime)s.%(msecs)03d | %(module)-10s [%(levelname)-8s] %(message)s'
    format_date = '%Y-%m-%d %H:%M:%S'
    formatter = logging.Formatter(format_entry, format_date)
    log_lvl = logging_level(numeric_level)

    # Configure root logger to a file
    logging.root.handlers = []
    logging.basicConfig(format='%(asctime)s.%(msecs)03d | %(module)-10s [%(levelname)-8s] %(message)s',\
                        level=logging.DEBUG ,\
                        filename='debug.log')

    if console :
        # Logging to sys.stderr
        consolehandler = logging.StreamHandler()
        consolehandler.setLevel(log_lvl)
        consolehandler.setFormatter(formatter)
        logging.getLogger("").addHandler(consolehandler)

    # Logging to file is provided
    if logfile :
        # Use rotating files : 1 per day, and all are kept (no rotation thus)
        filehandler = handlers.TimedRotatingFileHandler(logfile, when='d', interval=1, backupCount=0)
        filehandler.suffix = "%Y-%m-%d"
        # We can set here different log formats for the stderr output !
        filehandler.setLevel(logging.DEBUG)
        # use the same format as the file
        filehandler.setFormatter(formatter)
        # add the handler to the root logger
        logging.getLogger("").addHandler(filehandler)

    logging.info("Logging level set to %s", logging_level(numeric_level))

    # Have Gphot2 lgos in python logging module
    gp.use_python_logging()
    logging.getLogger('gphoto2').setLevel(logging.DEBUG)

    return logging

#################################
# Program options
#################################
def createParser():
    parser = argparse.ArgumentParser(epilog="If you have any questions : https://github.com/3isenHeiM/Photobooth",\
                                     description="This is %(prog)s, the programm to turn a RapsberryPi and an Arduino Uno into a photobooth")
    parser.add_argument('-v', '--verbose', action='count', default=3,\
                        help='Increases verbosity of logging (up to -vvvv).')
    parser.add_argument('-o', '--output_file', action='store', default='',\
                      help='Path/Name of log file (log level of 0). If no file specified, output only to stdout')
    parser.add_argument('-c', '--console', action='store_true',\
                      help='Enable logging output on STDOUT')
    parser.add_argument('-t', '--test', action='store_true', \
                        help='Run the program interactively to simulate Arduino communication. User will have to provide the commands to take pictures, etc...')
    parser.add_argument('-n', '--no-filter', action='store_false', dest="noFilter", \
                      help='Disables the instagram-like filter when processing the images.')
    return parser

def restart():
    args = sys.argv[:]
    logging.info('Re-spawning %s' % ' '.join(args))

    args.insert(0, sys.executable)
    time.sleep(1)
    os.chdir(_startup_cwd)
    os.execv(sys.executable, args)



#####################################
# MAIN
#####################################
parser       = createParser()
results      = parser.parse_args()
testMode     = results.test
_startup_cwd = os.getcwd()
pictureFolder = "images/jpg"
batt_lvl     = 25

pb_image.enableFilter = results.noFilter

# Init the Gphoto2 objects
context      = gp.Context()
camera       = gp.Camera()

arduino = None

log = configureLogging(results.verbose, results.output_file, results.console)

# Manage Ctrl+C
signal.signal(signal.SIGINT, signal_handler_quit)
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

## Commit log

2018-11-21 Added content on how to use the button and the darlington array
2018-11-21 Added autofocus of the camera at '1'
2018-11-22 Add PWM pin explanation
2018-11-26 Add breadboard wiring diagrams
    [breaboard.fzz]
2018-11-26 Typo in breadboard filenames
    [breadboard.fzz]
2018-11-26 Corrected pins on the Arduino
    [breadboard.fzz]
2018-11-26 Add link to make filters on python
2018-11-26 Pivoted Breadboard in the correct way ^^
    [breadboard.fzz]
2018-11-28 Corrected layout and pin number on arduino
    [breadboard.fzz]
2018-12-26 gitignore updated with logfiles, arduino tester script uploaded
2018-12-26 Reworked the HTTPserver part
    [photobooth.py]
2019-01-03 Added snippet for Serial Communcation with an Arduino
2019-01-03 Fixed Arduino_tester.py with the addition of the serial port config
    [Arduino_tester.py]
2019-01-03 Added breathing of the ButtonLED during countdown.
2019-01-04 Added error handling if images not present.
    [photobooth_image.py]
2019-01-04 Updated error handling for camra initialization.
    [photobooth_camera.py]
2019-01-04 Improved camera initialization. Updated serial reading with UTF decoding
2019-01-04 Added script for testing without Arduino (terminal interaction).
2019-01-26 testMode now works without Arduino with the camera.
2019-01-27 Added program to listen for command sent by the Arduino
2019-01-27 Changed USB port name, fixed serial port opening, and error handling
    [photobooth_serial.py]
2019-01-27 Made initSerial return arduino object. Fix serial comand name finding.
    [photobooth.py]
2019-01-27 Added error handling, and removed the wait before reading the command.
    [Arduino_tester.py]
2019-01-27 Deleted files that are non relevant anymore with current project state.
2019-01-27 Minor changes (delete commentaries, fixed typos)
    [photobooth_serial.py]
